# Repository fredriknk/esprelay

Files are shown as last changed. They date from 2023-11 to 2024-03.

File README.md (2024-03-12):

# ESPRELAY -_WORK IN PROGRESS-UNTESTED_-
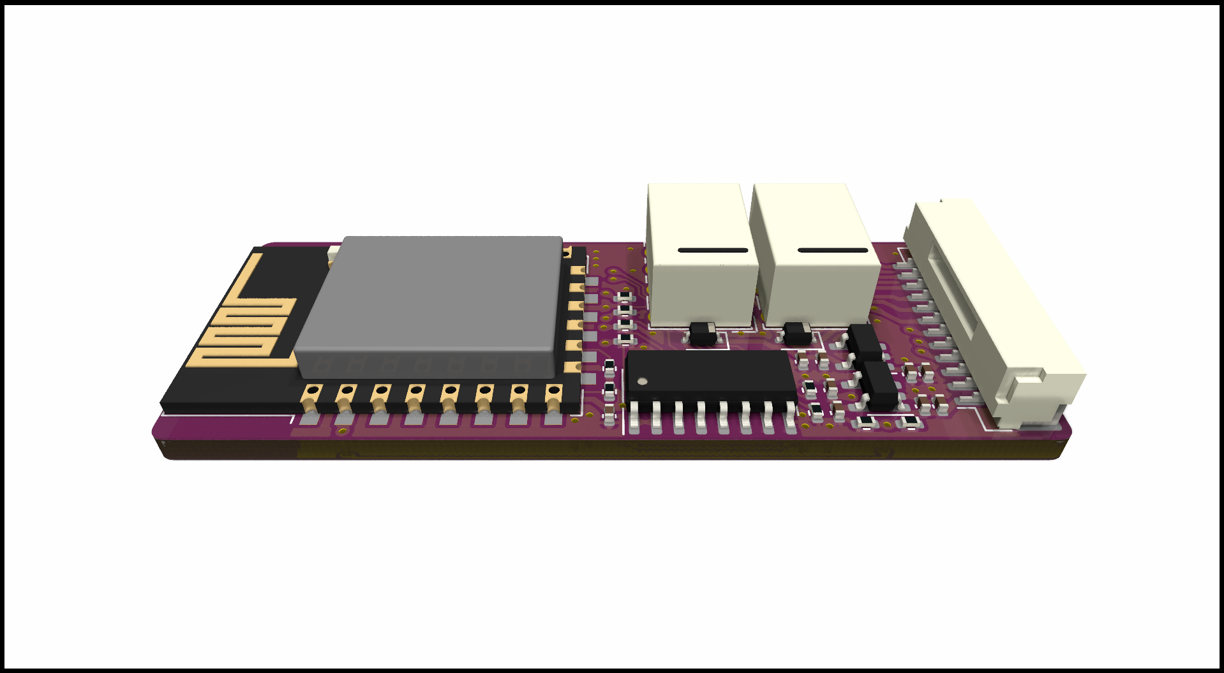
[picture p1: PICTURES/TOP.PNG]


ESP8266 small signal relay module utilizing an [ESP-12-F](./DOCUMENTATION/esp-12f_product_specification_en.pdf) wifi module for communication and MCU, and has two 2.5-25V inputs, and a single 25v, 100ma high speed open drain output through a [TBD062003](./DOCUMENTATION/2304140030_TOSHIBA-TBD62003AFWG_C114084.pdf) DMOS transistor array ic. The three relay outputs are capable of driving around 25V 500ma. 

Thanks to [u/PricelessToolkit/ESPClicker](https://github.com/PricelessToolkit/ESPClicker) for inspiration. If you need a ready to use product you should so head over to his [store](https://www.pricelesstoolkit.com/en/projects/32-espclicker-0741049314405.html) and buy his version.

[Schematic](./DOCUMENTATION/_schematic.pdf)

[Assembly IBOM](https://htmlpreview.github.io/?https://raw.githubusercontent.com/fredriknk/esprelay/main/PRODUCTION/ibom.html)

## Specifications
| **Parameter** | **Description** |
|---|---|
| _Input voltage_ | 5-15v |
| _Current_ | TBD Wifi: ##mA, Radio Off: ##mA, Deep sleep ##uA |  
| _Communication_ | 2.4ghz WIFI, Uart TTL |
| _Baudrate_ | 115200 |
| _PCB size_ | 20x65mm |
| _PCB info_ | 1.6mm FR4, HASL lead free, 4 layer (But works with 2) |
| _Case size_ | XxXxXmm TBD |

## Connector
| **Pin** | **GPIO**|**Description** |
|---|-----|---|
|_vcc_ | -|5-15v |
|_GND_ | -|  Ground  |
|_HI1_ | GPIO4 | 2.5-25v input |
|_HI1_ | GPIO5 | 2.5-25v input |
|_HO1_ | GPIO13 | 25v 100ma open drain output |
|_R1A_ | GPIO12  | Relay 1 COM |
|_R1NC_ | GPIO12 | Relay 1 Normally Closed |
|_R1NO_ | GPIO12 | Relay 1 Normally Open |
|_R2A_ | GPIO12  | Relay 1 COM |
|_R2NO_ | GPIO12 | Relay 1 Normally Open |
|_R3A_ | GPIO12  | Relay 1 COM |
|_R3NO_ | GPIO12 | Relay 1 Normally Open |

## PCB Pictures
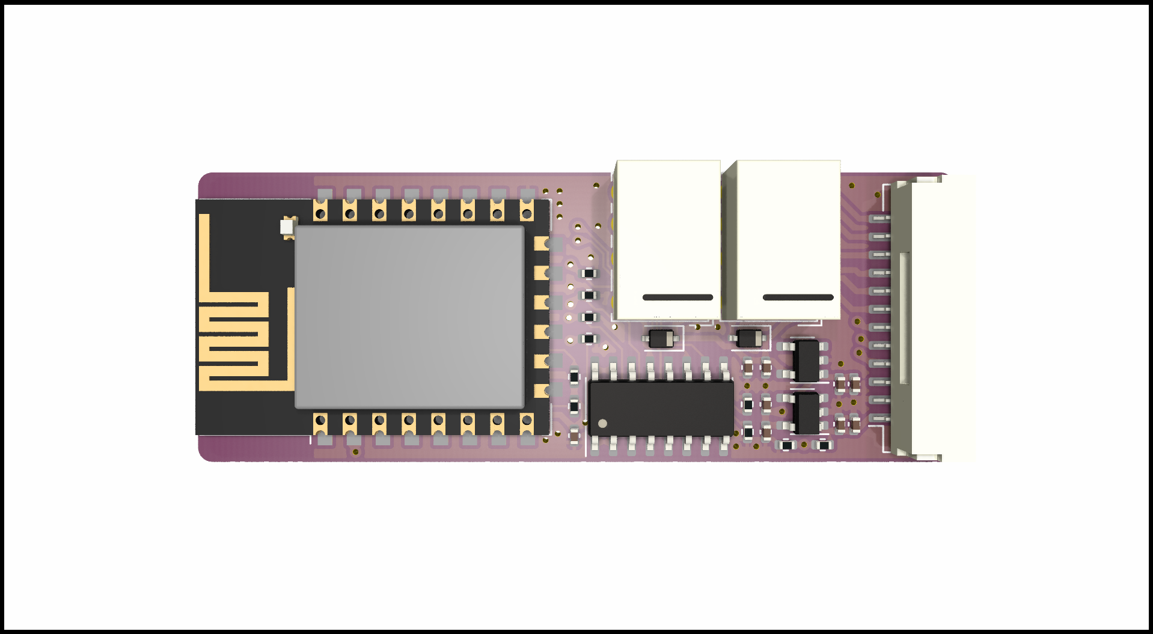
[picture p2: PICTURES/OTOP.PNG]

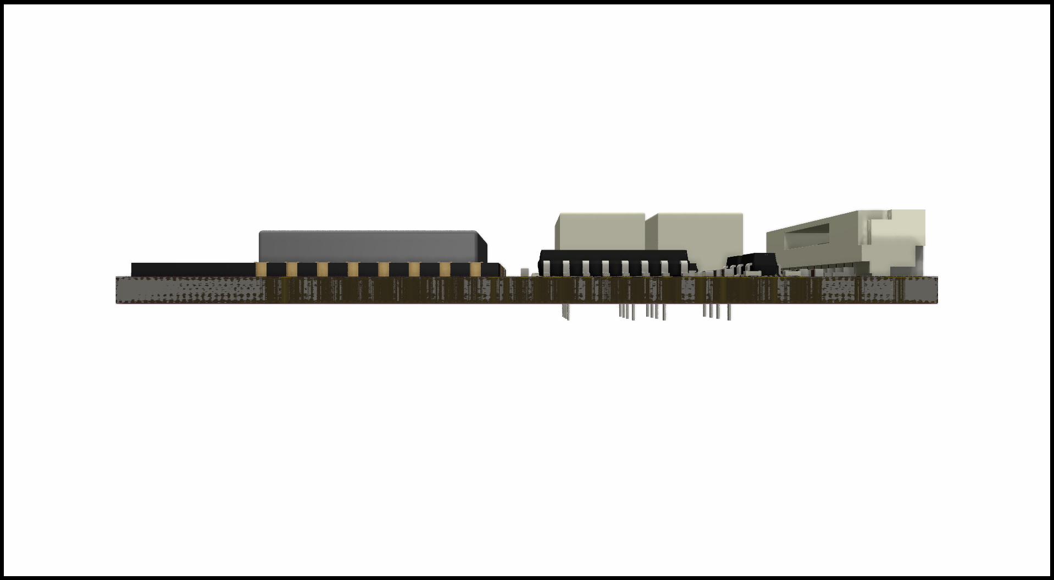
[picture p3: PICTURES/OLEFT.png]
Side

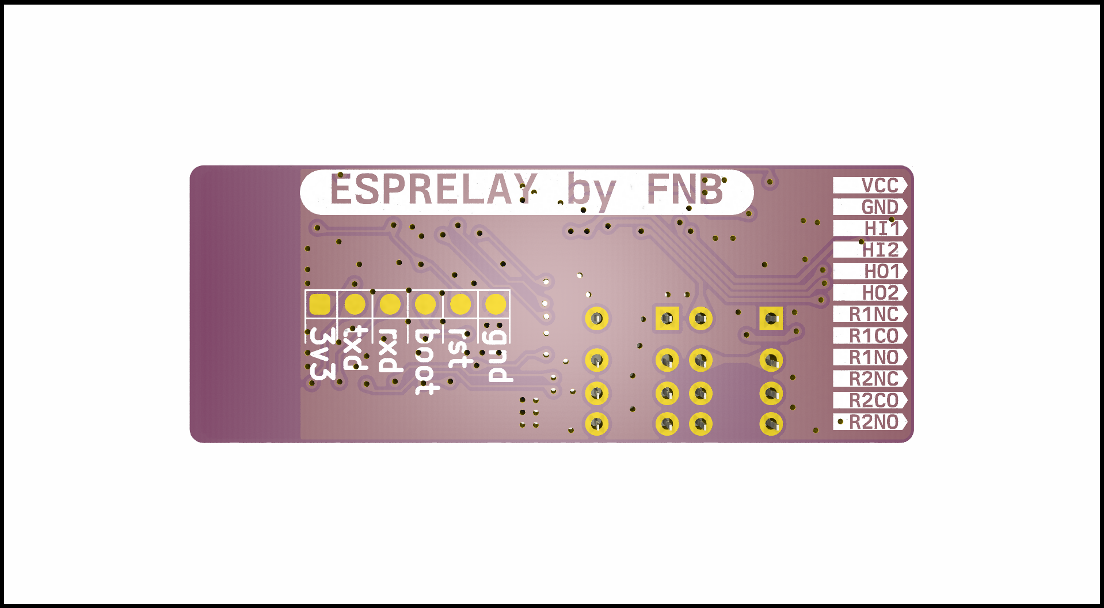
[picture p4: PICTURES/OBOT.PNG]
Back


## Homeassistant Implementation
TODO

## FIRST PRODUCTION PROTOTYPE
TODO

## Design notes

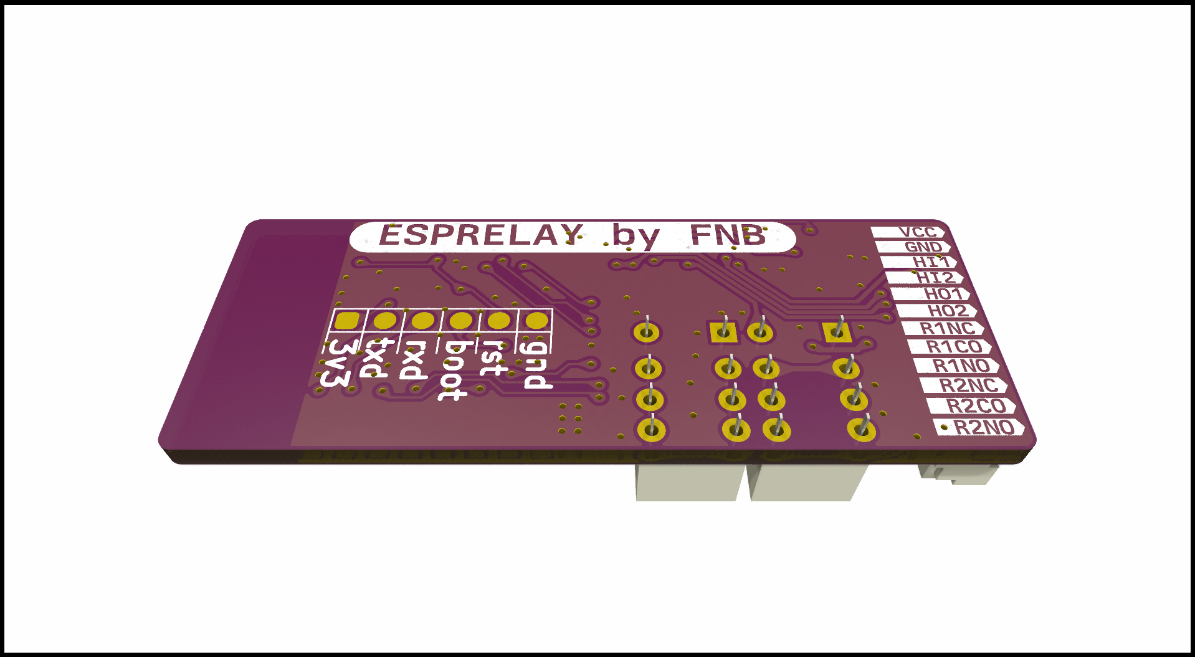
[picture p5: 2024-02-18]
PICTURES/BOTTOM.PNG

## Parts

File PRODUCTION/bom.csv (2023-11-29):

Designator | Footprint | Quantity | Value | LCSC Part #
C1, C2, C6, C7 | 0603 | 4 | 22uF | C96446
C10, C3, C4, C5, C8, C9 | 0603 | 6 | 0.1uF | C14663
D1, D2, D3 | D_SOD-323 | 3 | 1N4148WS | C2128
D4 | 0603 | 1 | KT-0603R | C2286
FID1, FID2, FID3 | Fiducial_1mm_Mask2mm | 3 | Fiducial
J1 | TestPoint_Pad_1.0x1.0mm_6pad | 1 | Conn_01x06_Pin
J2 | JST_GH_SM12B-GHS-TB_1x12-1MP_P1.25mm_Horizontal | 1 | Conn_01x14_Pin | C265421
K1, K2, K3 | Relay_DPDT_Omron_G6K-2P-Y | 3 | G6K-2P-Y | C80087
Q1 | 0603 | 1 | Q_Photo_NPN | C146233
R1, R10, R11, R12, R2, R3, R4, R5, R7, R8, R9 | 0603 | 11 | 10K | C25804
R13, R6 | 0603 | 2 | 470 | C23179
SW1 | SW_SPST_TS-1088-AR | 1 | SW_SPST | C720477
U1 | SOT-23-5 | 1 | SPX3819M5-L-5-0 | C13417
U2 | SOT-23-5 | 1 | SPX3819M5-L-3-3 | C9055
U3 | ESP-12E | 1 | ESP-12F | C82891
U4 | Sensirion_DFN-4-1EP_2x2mm_P1mm_EP0.7x1.6mm | 1 | SHTC3 | C194656
U5 | SOIC-16_3.9x9.9mm_P1.27mm | 1 | TBD62003AFWG | C114084

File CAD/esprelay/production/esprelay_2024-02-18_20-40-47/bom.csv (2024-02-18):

Designator | Footprint | Quantity | Value | LCSC Part #
C1, C2, C6, C7 | 0402 | 4 | 1uF | C52923
C3, C4, C5, C8, C9 | 0402 | 5 | 0.1uF | C307331
D1, D2 | D_SOD-323 | 2 | 1N4148WS | C2128
J1 | TestPoint_Pad_1.0x1.0mm_6pad | 1 | Conn_01x06_Pin
J2 | JST_GH_SM12B-GHS-TB_1x12-1MP_P1.25mm_Horizontal | 1 | SM12B-GHS-TB(LF)(SN) | C265421
K1, K2 | Relay_DPDT_Omron_G6K-2P-Y | 2 | G6K-2P-Y | C80087
R1, R10, R11, R12, R2, R7, R8, R9 | 0402 | 8 | 10K | C25744
R3 | 0402 | 1 | 13.7k | C25854
R6 | 0402 | 1 | 316k | C25777
U1 | SOT-23-5 | 1 | DS8242-33S5 | C5884133
U2 | SOT-23-5 | 1 | DS8242-50S3 | C5884139
U3 | ESP-12E | 1 | ESP-12F | C82891
U5 | SOIC-16_3.9x9.9mm_P1.27mm | 1 | TBD62003AFWG | C114084

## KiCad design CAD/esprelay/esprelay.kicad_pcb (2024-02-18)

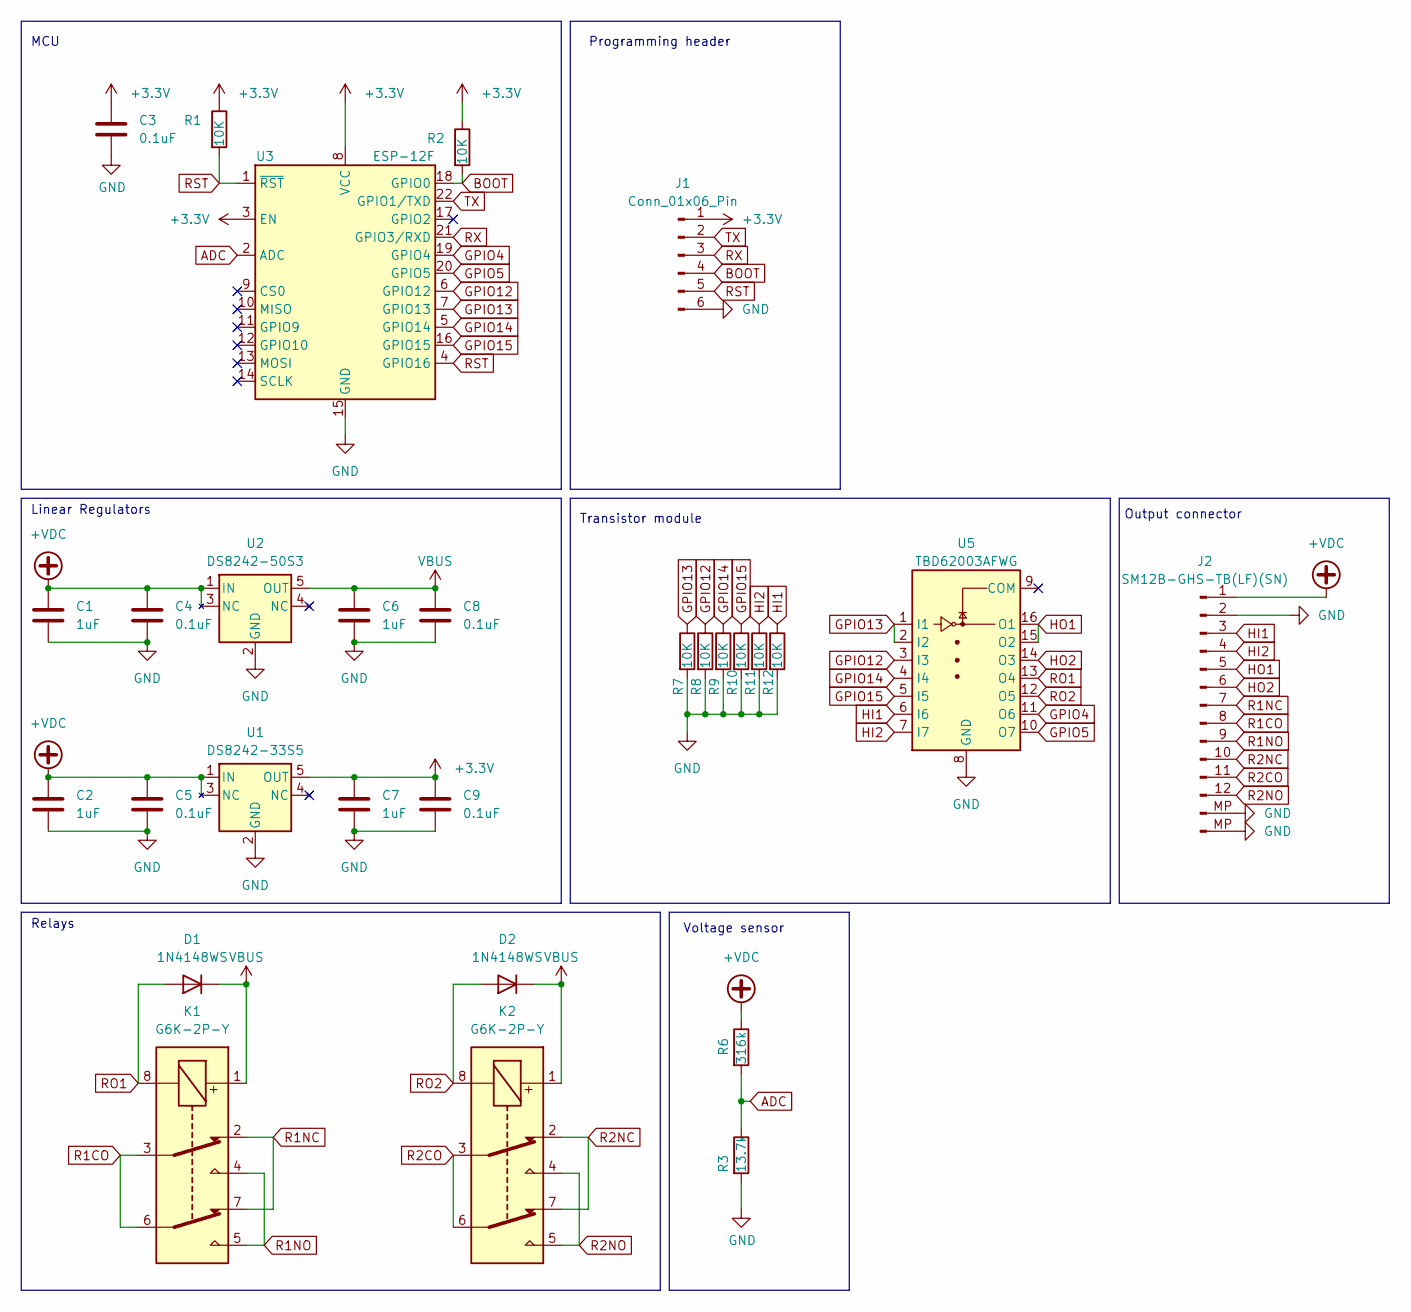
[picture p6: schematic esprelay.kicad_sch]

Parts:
C1, C2, C6, C7: 1uF; C_0402_1005Metric; LCSC Part # C52923
C3, C4, C5, C8, C9: 0.1uF; C_0402_1005Metric; LCSC Part # C307331
D1, D2: 1N4148WS; D_SOD-323; LCSC Part # C2128
J1: Conn_01x06_Pin; TestPoint_Pad_1.0x1.0mm_6pad
J2: SM12B-GHS-TB(LF)(SN); JST_GH_SM12B-GHS-TB_1x12-1MP_P1.25mm_Horizontal; LCSC Part # C265421
K1, K2: G6K-2P-Y; Relay_DPDT_Omron_G6K-2P-Y; LCSC Part # C80087
R1, R2, R7, R8, R9, R10, R11, R12: 10K; R_0402_1005Metric; LCSC Part # C25744
R3: 13.7k; R_0402_1005Metric; LCSC Part # C25854
R6: 316k; R_0402_1005Metric; LCSC Part # C25777
U1: DS8242-33S5; SOT-23-5; LCSC Part # C5884133
U2: DS8242-50S3; SOT-23-5; LCSC Part # C5884139
U3: ESP-12F; ESP-12E; LCSC Part # C82891
U5: TBD62003AFWG; SOIC-16_3.9x9.9mm_P1.27mm; LCSC Part # C114084

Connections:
+3.3V: C3.1, C7.1, C9.1, J1.1, R1.1, R2.1, U1.5 (OUT), U3.3 (EN), U3.8 (VCC)
+VDC: C1.1, C2.1, C4.2, C5.2, J2.1, R6.1, U1.1 (IN), U1.3 (NC), U2.1 (IN), U2.3 (NC)
ADC: R3.1, R6.2, U3.2 (ADC)
BOOT: J1.4, R2.2, U3.18 (GPIO0)
GND: C1.2, C2.2, C3.2, C4.1, C5.1, C6.2, C7.2, C8.2, C9.2, J1.6, J2.2, J2.MP (Pin_13), R3.2, R7.2, R8.2, R9.2, R10.2, R11.2, R12.2, U1.2 (GND), U2.2 (GND), U3.15 (GND), U5.8 (GND)
GPIO4: U3.19 (GPIO4), U5.11 (O6)
GPIO5: U3.20 (GPIO5), U5.10 (O7)
GPIO12: R8.1, U3.6 (GPIO12), U5.3 (I3)
GPIO13: R7.1, U3.7 (GPIO13), U5.1 (I1), U5.2 (I2)
GPIO14: R9.1, U3.5 (GPIO14), U5.4 (I4)
GPIO15: R10.1, U3.16 (GPIO15), U5.5 (I5)
HI1: J2.3, R12.1, U5.6 (I6)
HI2: J2.4, R11.1, U5.7 (I7)
HO1: J2.5, U5.15 (O2), U5.16 (O1)
HO2: J2.6, U5.14 (O3)
R1CO: J2.8, K1.3, K1.6
R1NC: J2.7, K1.2, K1.7
R1NO: J2.9, K1.4, K1.5
R2CO: J2.11, K2.3, K2.6
R2NC: J2.10, K2.2, K2.7
R2NO: J2.12, K2.4, K2.5
RO1: D1.2 (A), K1.8, U5.13 (O4)
RO2: D2.2 (A), K2.8, U5.12 (O5)
RST: J1.5, R1.2, U3.1 (~RST), U3.4 (GPIO16)
RX: J1.3, U3.21 (GPIO3/RXD)
TX: J1.2, U3.22 (GPIO1/TXD)
VBUS: C6.1, C8.1, D1.1 (K), D2.1 (K), K1.1, K2.1, U2.5 (OUT)

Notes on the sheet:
Transistor module
Linear Regulators
MCU
Output connector
Programming header
Relays
Voltage sensor

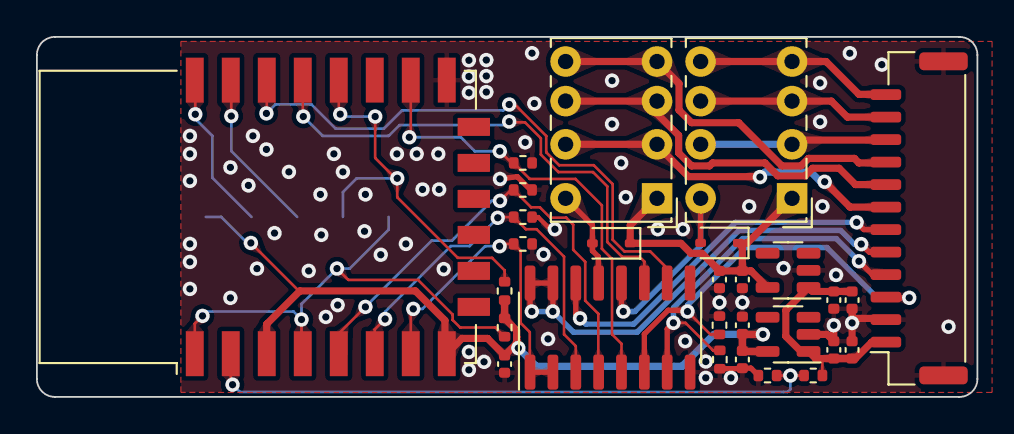
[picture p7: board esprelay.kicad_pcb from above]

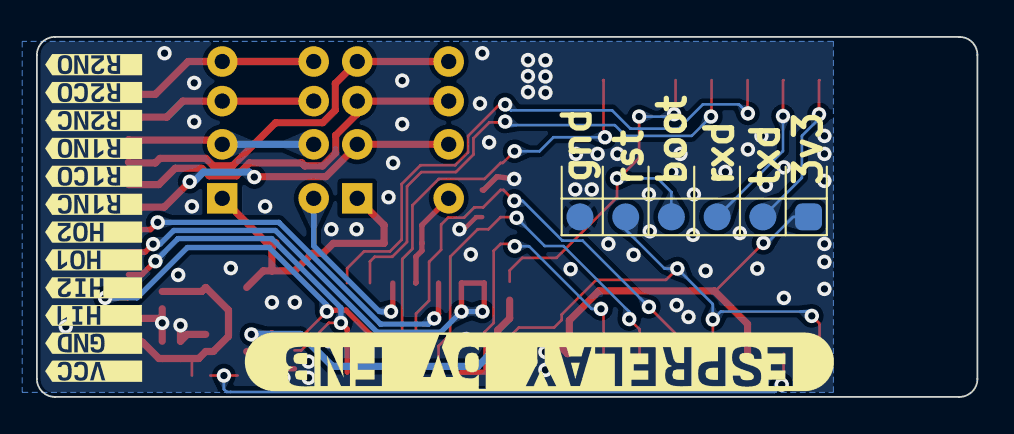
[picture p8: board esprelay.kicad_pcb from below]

Board: 2 copper layers, 52.2 x 20.0 mm, 42 parts (14 on the bottom side), 27 nets.

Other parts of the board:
kibuzzard-65CFDA91: G***; kibuzzard-65CFDA91
kibuzzard-65CFDAA0: G***; kibuzzard-65CFDAA0
kibuzzard-65CFDAA7: G***; kibuzzard-65CFDAA7
kibuzzard-65CFDAAD: G***; kibuzzard-65CFDAAD
kibuzzard-65CFDAB5: G***; kibuzzard-65CFDAB5
kibuzzard-65CFDABC: G***; kibuzzard-65CFDABC
kibuzzard-65666C6B: G***; kibuzzard-65666C6B
kibuzzard-65666C7B: G***; kibuzzard-65666C7B
kibuzzard-65666C71: G***; kibuzzard-65666C71
kibuzzard-65666C76: G***; kibuzzard-65666C76
kibuzzard-65666C87: G***; kibuzzard-65666C87
kibuzzard-65666CB7: G***; kibuzzard-65666CB7
kibuzzard-6566713E: G***; kibuzzard-6566713E

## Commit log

2023-11-24 Feat: Changed module to ESP12F
    [CONNECTORS.kicad_sch, LINEAR_REG.kicad_sch, esprelay.kicad_sch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]
2023-11-27 Feat: Started Routing
    [ADC.kicad_sch, ADS8075.kicad_sch, CONNECTORS.kicad_sch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]
2023-11-28 Feat: Pretty much complete
    [esprelay.kicad_pcb, esprelay.kicad_sch]
2023-11-28 Feat: Fixed lcsc product numbers
    [esprelay.kicad_pcb, esprelay.kicad_sch]
2023-11-28 Feat: Finished silkscreen
    [bom.csv, designators.csv, esprelay.kicad_pcb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]
2023-11-28 Fix: Minor trace adjustment
    [esprelay.kicad_pcb]
2023-11-29 Feat: JLC purchase
    [bom.csv, designators.csv, esprelay.kicad_pcb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]
2023-11-30 Feat: 4 layer,readme and cleanup
    [bom.csv, designators.csv, esprelay.kicad_pcb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]
2023-11-30 Feat: Readme and documentation work
    [esprelay.kicad_sch]
